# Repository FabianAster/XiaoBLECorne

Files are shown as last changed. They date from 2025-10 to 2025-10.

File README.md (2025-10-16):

# XiaoCorne (Bluetooth)

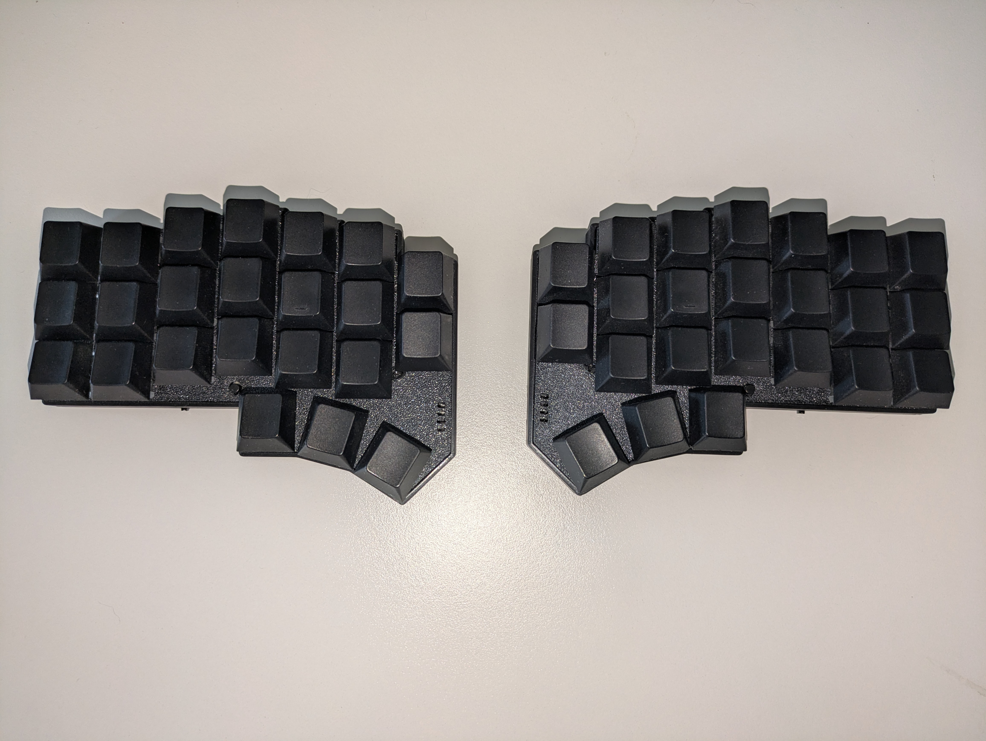
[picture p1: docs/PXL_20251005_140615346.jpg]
XiaoCorne


A compact, wireless keyboard inspired by the Corne v4 (foostan/crkbd), rebuilt around a Seeed XIAO BLE.
My goal was to create a wireless keyboard without any visible microcontroller and to minimize unused space.
For reading the battery level, a fully analog indicator with 4 LEDs is on the top side of the PCB.

Firmware and ZMK config are here: https://github.com/FabianAster/seedCorneModule

I made the PCB with CircuitMaker, not with KiCad, so I can only share the link to it: https://workspace.circuitmaker.com/Projects/Details/9C26B9D0-BD64-4451-B20A-DC635F824EC1
Gerber files to order the PCB are in the repo.

## Some More Images

### PCB Bottom and Battery

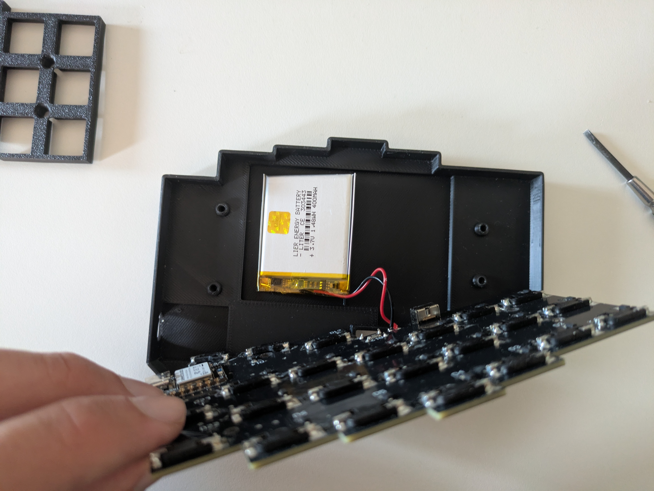
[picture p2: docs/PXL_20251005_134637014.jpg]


For the case to fit, it needs to be a 10345 LiPo battery. Charging is handled by the Seeeduino XIAO BLE.
The LEDs on the top side need to be red, since I used simple 358 op-amps for voltage comparison, and they drop some voltage at their output.

### PCB Top

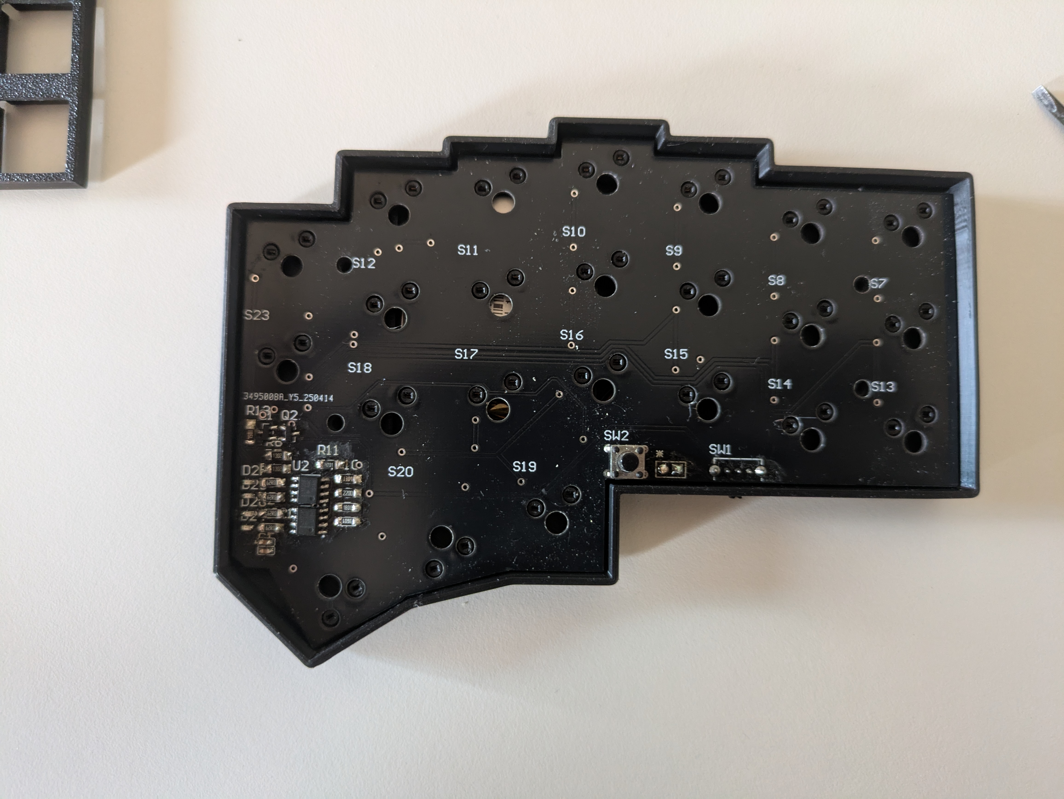
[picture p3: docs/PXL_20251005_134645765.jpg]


### Comparison with Original Corne V4 on the Left, This One on the Right

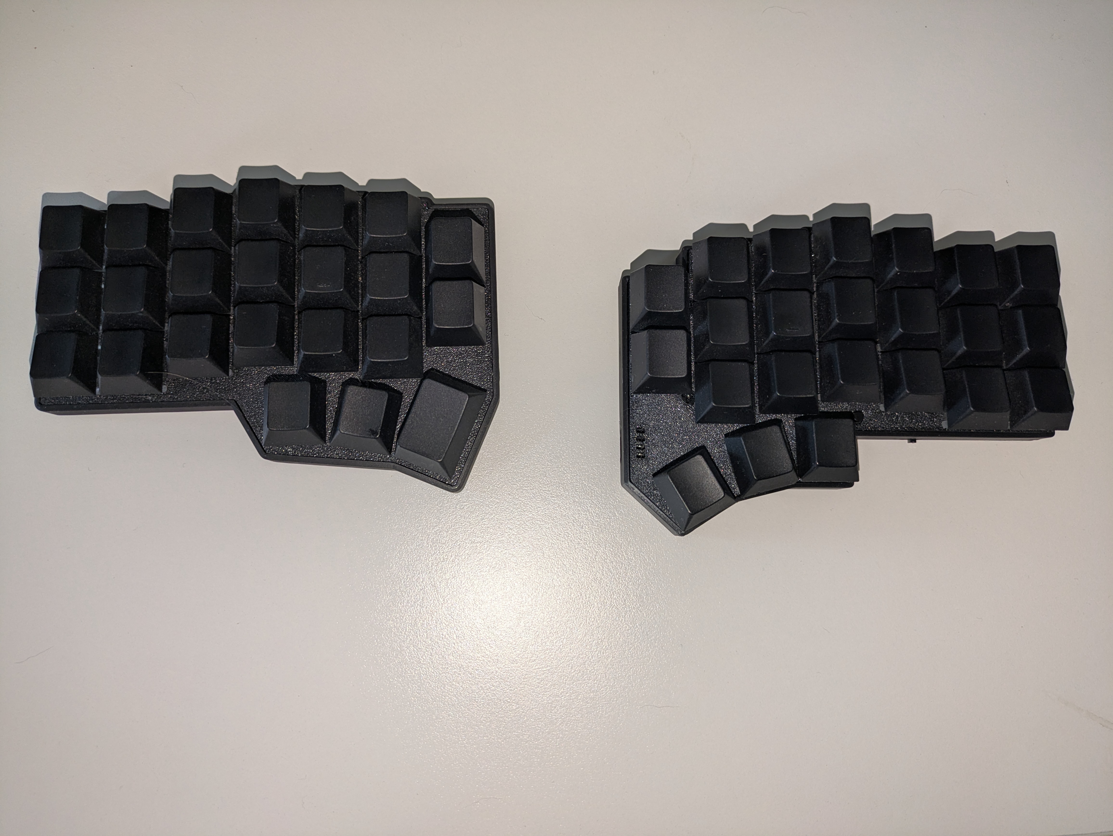
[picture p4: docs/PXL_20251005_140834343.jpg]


## Part List

| Quantity | Part | Package/Type |
| --- | --- | --- |
| 4 | 100nF capacitor | 0603 |
| 4 | AO3401A MOSFET | SOT-23 |
| 2 | Switch (SK12D07VG4NSPA) | - |
| 46 | Hotswap MX sockets | - |
| 46 | SMD Diode (1N4007L) | SOD-123 |
| 2 | Seeed Xiao BLE (nRF52840) | - |
| 4 | LM358 SMD | SOIC-8 |
| 2 | Button | - |
| 8 | Red LED | 0603 |
| 2 | 4.7k Ohm resistor | 1206 |
| 6 | 10k Ohm resistor | 1206 |
| 2 | 130 Ohm resistor | 1206 |
| 2 | 220 Ohm resistor | 1206 |
| 2 | 180 Ohm resistor | 1206 |
| 2 | 3.6k Ohm resistor | 1206 |

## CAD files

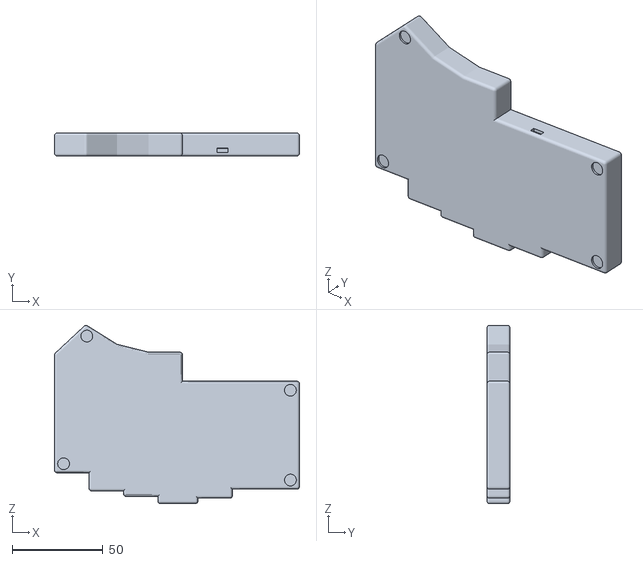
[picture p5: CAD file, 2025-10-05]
case/caseRight.stl
135.0 x 12.6 x 98.3

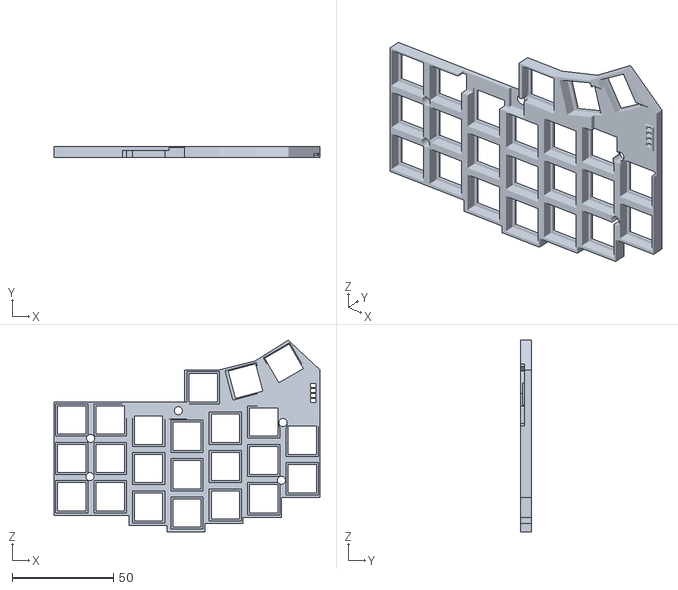
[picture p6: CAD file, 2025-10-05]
case/gridLeft.stl
131.6 x 5.40 x 94.8

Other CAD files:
case/gridRight.stl
case/caseLeft.stl
